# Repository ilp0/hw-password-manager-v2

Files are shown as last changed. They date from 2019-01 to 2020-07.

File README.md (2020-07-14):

# HW Password Manager V2

[Youtube Video](https://www.youtube.com/watch?v=QssnJo2gxCg)

## Libraries needed:

[SSD1306Ascii](https://github.com/greiman/SSD1306Ascii)

[RFID](https://github.com/miguelbalboa/rfid)

[SD](https://github.com/arduino-libraries/SD)

[rBase64](https://github.com/boseji/rBASE64)

[DigitalIO](https://github.com/greiman/DigitalIO)

[SPI](https://www.arduino.cc/en/reference/SPI)

## Wiring

### SSD1306 display

| SSD1306 Pin 	| Pro Micro Pin 	|
|-	|-	|
| GND 	| GND 	|
| VCC 	| 5V 	|
| SCL 	| SCL 	|
| SDA 	| SDA 	|

### RC522 RFID 

| RC522 	| Pro Micro Pin 	|
|-	|-	|
| SS(component most likely says SDA) 	| 8 	|
| MISO 	| MISO (14) 	|
| MOSI 	| MOSI (16) 	|
| SCK 	| SCLK (15) 	|
| RST 	| 4 	|
| GND 	| GND 	|
| 3.3V 	| 3.3V 	|

### Micro SD card reader

| SD Card reader 	| Pro Micro Pin 	|
|-	|-	|
| SS 	| 10 	|
| MISO 	| MISO (14) 	|
| MOSI 	| MOSI (16) 	|
| SCK 	| SCLK (15) 	|
| GND 	| GND 	|
| 3.3V 	| 3.3V 	|

### Joystick

| Joystick | Pro Micro Pin |
|- |- |
| VCC | VCC|
| Y | A1 |
| GND | GND |
| X | A0 |

### Push buitton

Pro Micro Pin 9

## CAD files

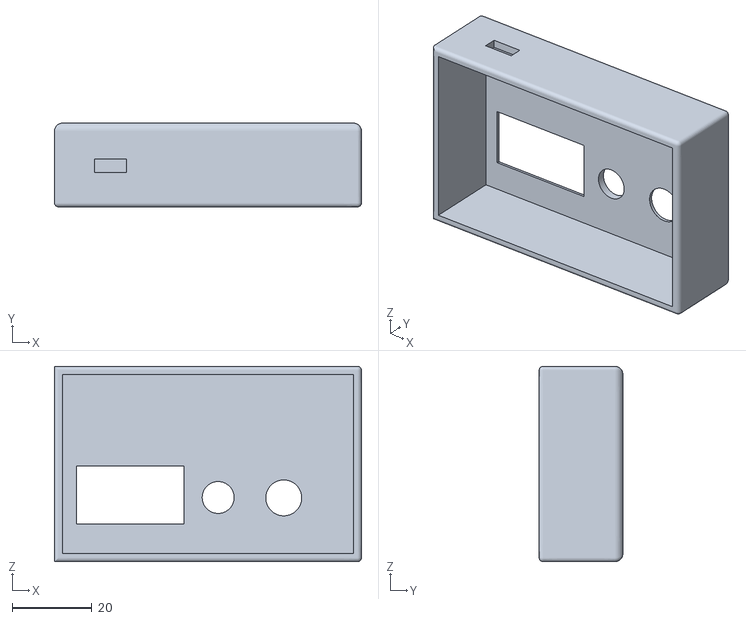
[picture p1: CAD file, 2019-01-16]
3d/password-manager-v2-case-top.stl
77.0 x 21.0 x 49.0

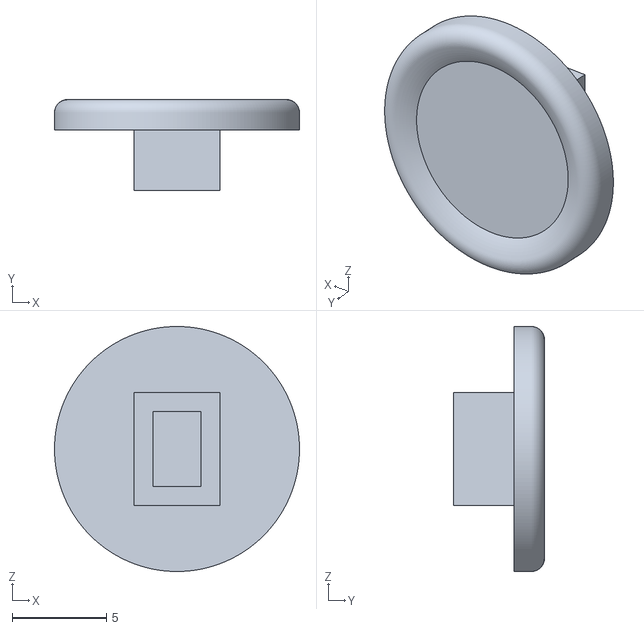
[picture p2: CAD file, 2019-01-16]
3d/password-manager-v2-thumbstick.stl
13.0 x 4.83 x 13.0

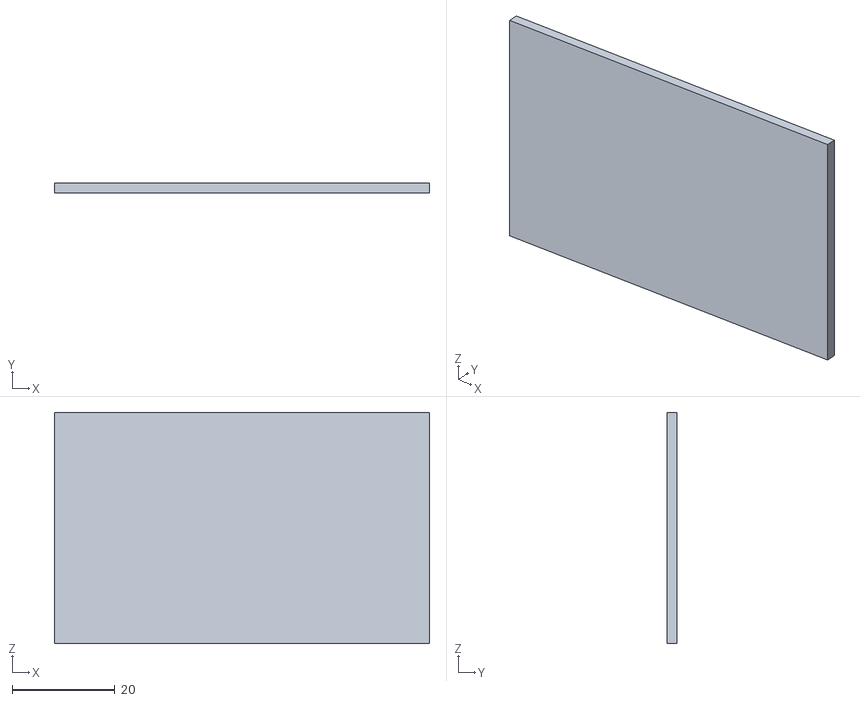
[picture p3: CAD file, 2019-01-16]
3d/password-manager-v2-case-bottom.stl
73.0 x 2.00 x 45.0

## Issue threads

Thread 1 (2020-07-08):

Rfid library

Zeskye, 2020-07-08:
First of all thanks for your quick reply. I have downloaded and installed all library that you put in the readme, but after compilation of the hardware-password-manager-V2.ino, im getting a lot of error, first of all the RFID.h library is not found because the library linked for the RFID is the MFRC522.h, and even by replacing RFID.h by MFRC522.h it's not working.

 Arduino : 1.8.12 (Windows 10), Carte : "Arduino Micro"

In file included from C:\Program Files (x86)\Arduino\libraries\SD\src/utility/Sd2Card.h:26:0,

                 from C:\Program Files (x86)\Arduino\libraries\SD\src/utility/SdFat.h:29,

                 from C:\Program Files (x86)\Arduino\libraries\SD\src/SD.h:20,

                 from C:\Users\Zeskye\Documents\hw-password-manager-v2-master_2\hw-password-manager-v2-master\hardware-password-manager-v2\hardware-password-manager-v2.ino:15:

C:\Program Files (x86)\Arduino\libraries\SD\src/utility/Sd2PinMap.h:463:9: error: ambiguating new declaration of 'uint8_t badPinNumber()'

 uint8_t badPinNumber(void)

         ^~~~~~~~~~~~

In file included from C:\Users\Zeskye\Documents\Arduino\libraries\DigitalIO-master\src/DigitalIO.h:31:0,

                 from C:\Users\Zeskye\Documents\hw-password-manager-v2-master_2\hw-password-manager-v2-master\hardware-password-manager-v2\hardware-password-manager-v2.ino:9:

C:\Users\Zeskye\Documents\Arduino\libraries\DigitalIO-master\src/DigitalPin.h:47:6: note: old declaration 'void badPinNumber()'

 void badPinNumber(void)

      ^~~~~~~~~~~~

In file included from C:\Program Files (x86)\Arduino\libraries\SD\src/utility/Sd2Card.h:26:0,

                 from C:\Program Files (x86)\Arduino\libraries\SD\src/utility/SdFat.h:29,

                 from C:\Program Files (x86)\Arduino\libraries\SD\src/SD.h:20,

                 from C:\Users\Zeskye\Documents\hw-password-manager-v2-master_2\hw-password-manager-v2-master\hardware-password-manager-v2\hardware-password-manager-v2.ino:15:

C:\Program Files (x86)\Arduino\libraries\SD\src/utility/Sd2PinMap.h: In function 'uint8_t getPinMode(uint8_t)':

C:\Program Files (x86)\Arduino\libraries\SD\src/utility/Sd2PinMap.h:471:25: error: void value not ignored as it ought to be

     return badPinNumber();

                         ^

C:\Program Files (x86)\Arduino\libraries\SD\src/utility/Sd2PinMap.h: In function 'uint8_t fastDigitalRead(uint8_t)':

C:\Program Files (x86)\Arduino\libraries\SD\src/utility/Sd2PinMap.h:487:9: error: ambiguating new declaration of 'uint8_t fastDigitalRead(uint8_t)'

 uint8_t fastDigitalRead(uint8_t pin) {

         ^~~~~~~~~~~~~~~

In file included from C:\Users\Zeskye\Documents\Arduino\libraries\DigitalIO-master\src/DigitalIO.h:31:0,

                 from C:\Users\Zeskye\Documents\hw-password-manager-v2-master_2\hw-password-manager-v2-master\hardware-password-manager-v2\hardware-password-manager-v2.ino:9:

C:\Users\Zeskye\Documents\Arduino\libraries\DigitalIO-master\src/DigitalPin.h:127:6: note: old declaration 'bool fastDigitalRead(uint8_t)'

 bool fastDigitalRead(uint8_t pin) {

      ^~~~~~~~~~~~~~~

In file included from C:\Program Files (x86)\Arduino\libraries\SD\src/utility/Sd2Card.h:26:0,

                 from C:\Program Files (x86)\Arduino\libraries\SD\src/utility/SdFat.h:29,

                 from C:\Program Files (x86)\Arduino\libraries\SD\src/SD.h:20,

                 from C:\Users\Zeskye\Documents\hw-password-manager-v2-master_2\hw-password-manager-v2-master\hardware-password-manager-v2\hardware-password-manager-v2.ino:15:

C:\Program Files (x86)\Arduino\libraries\SD\src/utility/Sd2PinMap.h:491:25: error: void value not ignored as it ought to be

     return badPinNumber();

                         ^

In file included from C:\Users\Zeskye\Documents\Arduino\libraries\SSD1306Ascii-master\src/SSD1306AsciiAvrI2c.h:26:0,

                 from C:\Users\Zeskye\Documents\hw-password-manager-v2-master_2\hw-password-manager-v2-master\hardware-password-manager-v2\hardware-password-manager-v2.ino:19:

C:\Users\Zeskye\Documents\Arduino\libraries\SSD1306Ascii-master\src/utility/AvrI2c.h: At global scope:

C:\Users\Zeskye\Documents\Arduino\libraries\SSD1306Ascii-master\src/utility/AvrI2c.h:29:15: error: redefinition of 'const uint8_t I2C_READ'

 uint8_t const I2C_READ = 1;

               ^~~~~~~~

In file included from C:\Users\Zeskye\Documents\Arduino\libraries\DigitalIO-master\src/DigitalIO.h:32:0,

                 from C:\Users\Zeskye\Documents\hw-password-manager-v2-master_2\hw-password-manager-v2-master\hardware-password-manager-v2\hardware-password-manager-v2.ino:9:

C:\Users\Zeskye\Documents\Arduino\libraries\DigitalIO-master\src/I2cConstants.h:51:15: note: 'const uint8_t I2C_READ' previously defined here

 const uint8_t I2C_READ = 1;

               ^~~~~~~~

In file included from C:\Users\Zeskye\Documents\Arduino\libraries\SSD1306Ascii-master\src/SSD1306AsciiAvrI2c.h:26:0,

                 from C:\Users\Zeskye\Documents\hw-password-manager-v2-master_2\hw-password-manager-v2-master\hardware-password-manager-v2\hardware-password-manager-v2.ino:19:

C:\Users\Zeskye\Documents\Arduino\libraries\SSD1306Ascii-master\src/utility/AvrI2c.h:32:15: error: redefinition of 'const uint8_t I2C_WRITE'

 uint8_t const I2C_WRITE = 0;

               ^~~~~~~~~

In file included from C:\Users\Zeskye\Documents\Arduino\libraries\DigitalIO-master\src/DigitalIO.h:32:0,

                 from C:\Users\Zeskye\Documents\hw-password-manager-v2-master_2\hw-password-manager-v2-master\hardware-password-manager-v2\hardware-password-manager-v2.ino:9:

C:\Users\Zeskye\Documents\Arduino\libraries\DigitalIO-master\src/I2cConstants.h:54:15: note: 'const uint8_t I2C_WRITE' previously defined here

 const uint8_t I2C_WRITE = 0;

               ^~~~~~~~~

hardware-password-manager-v2:46:9: error: expected constructor, destructor, or type conversion before '(' token

 mfrc522 (RFID_SS_PIN, RST_PIN) ;

         ^

C:\Users\Zeskye\Documents\hw-password-manager-v2-master_2\hw-password-manager-v2-master\hardware-password-manager-v2\hardware-password-manager-v2.ino: In function 'void setup()':

hardware-password-manager-v2:81:3: error: 'mfrc522' was not declared in this scope

   mfrc522.init();

   ^~~~~~~

C:\Users\Zeskye\Documents\hw-password-manager-v2-master_2\hw-password-manager-v2-master\hardware-password-manager-v2\hardware-password-manager-v2.ino: In function 'void temp()':

hardware-password-manager-v2:114:7: error: 'mfrc522' was not declared in this scope

   if (mfrc522.readCardSerial())

       ^~~~~~~

hardware-password-manager-v2:122:3: error: 'mfrc522' was not declared in this scope

   mfrc522.halt();

   ^~~~~~~

C:\Users\Zeskye\Documents\hw-password-manager-v2-master_2\hw-password-manager-v2-master\hardware-password-manager-v2\hardware-password-manager-v2.ino: In function 'void generateCreds()':

C:\Users\Zeskye\Documents\hw-password-manager-v2-master_2\hw-password-manager-v2-master\hardware-password-manager-v2\hardware-password-manager-v2.ino:258:21: warning: ISO C++ forbids converting a string constant to 'char*' [-Wwrite-strings]

   char *alphabeth = "abcdefghijklmnopqrstuvwxyzABCDEFGHIJKLMNOPQRSTUVWXYZ0123456789'?^&/%$£-+";

                     ^~~~~~~~~~~~~~~~~~~~~~~~~~~~~~~~~~~~~~~~~~~~~~~~~~~~~~~~~~~~~~~~~~~~~~~~~~~

C:\Users\Zeskye\Documents\hw-password-manager-v2-master_2\hw-password-manager-v2-master\hardware-password-manager-v2\hardware-password-manager-v2.ino:260:16: warning: ISO C++ forbids converting a string constant to 'char*' [-Wwrite-strings]

   char *pass = "";

                ^~

C:\Users\Zeskye\Documents\hw-password-manager-v2-master_2\hw-password-manager-v2-master\hardware-password-manager-v2\hardware-password-manager-v2.ino:278:16: warning: unknown escape sequence: '\;'

     newPass += "\;";

                ^~~~

C:\Users\Zeskye\Documents\hw-password-manager-v2-master_2\hw-password-manager-v2-master\hardware-password-manager-v2\hardware-password-manager-v2.ino: In function 'void loop()':

hardware-password-manager-v2:384:10: error: 'mfrc522' was not declared in this scope

     if (!mfrc522.isCard())

          ^~~~~~~

Plusieurs bibliothèque trouvées pour "SD.h"
Utilisé : C:\Program Files (x86)\Arduino\libraries\SD
Non utilisé : C:\Users\Zeskye\Documents\Arduino\libraries\SD-master
exit status 1
expected constructor, destructor, or type conversion before '(' token

Ce rapport pourrait être plus détaillé avec
l'option "Afficher les résultats détaillés de la compilation"
activée dans Fichier -> Préférences.

ilp0, 2020-07-14:
Hey Zeskye!

I added the RFID library I used. I used an old version of the linked library.

Also, if you're using a Sparkfun Pro Micro(or a clone), have you gone through the [installation steps](https://learn.sparkfun.com/tutorials/pro-micro--fio-v3-hookup-guide)? You should have the Pro Micro board selected when you build/verify the code.

Closed 2020-08-12.

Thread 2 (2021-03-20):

BOARD ERROR

unkn0wn-wifi, 2021-03-20:
Hi there,
My name is sanjai and im a cyber security researcher student, i have a youtube channel related to this https://www.youtube.com/channel/UCrxx_lAmF_Lv5laNLnPBIPw

So ive recently came upon your project and have come really interested in it, so i gathered all the parts and bought them on aliexpress, after waiting for a month all of them arrived i stuck them ont a breadboard and tried uploading the code to recieve a

"Error compiling for Sparkfun Pro Micro"

So i need your help can you please guide me through how to mitigate this issue and some steps on how to set this up as there is very little documentation on how to set this up plz as after assembling i will be reviewing this on my youtube channel
, if you can please contact me via discord ill be happy to speak to you! sanjai#1186

Looking forward for your reply

Sanjai

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

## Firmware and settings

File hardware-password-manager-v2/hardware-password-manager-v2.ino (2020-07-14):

/*
    HARDWARE PASSWORD MANAGER
    Author: Ilpo Loikkanen
*/


//base64
#include <rBase64.h>

//software SPI
#include <DigitalIO.h>

// RC522 rfid
#include "RFID_lib/rfid.h"

//SD card
#include <SD.h>

//128x64 OLED display. Using ascii library for smaller size
#include <SSD1306Ascii.h>
#include <SSD1306AsciiAvrI2c.h>
#include <SSD1306init.h>

//KB and mouse emulation
#include <Keyboard.h>
#include <Mouse.h>

//hardware SPI
#include <SPI.h>

//RFID PINS
#define RFID_SS_PIN 8
#define RST_PIN 4

//SD CARD PIN
#define SD_SS_PIN 10

//SCREEN STUFF
#define I2C_ADDRESS 0x3C
SSD1306AsciiAvrI2c display;

//other defines
#define PASSWORD_SIZE  8
#define PASS_ARR_SIZE  20
#define STRING_ARRAY_SIZE(x) sizeof(x)/sizeof(x[0])

//RFID STUFF
RFID mfrc522 (RFID_SS_PIN, RST_PIN) ;
unsigned long RFID;
String readid;

//passwords and cards
String card1 = ""; //card
String card2 = ""; //keychain
byte password[PASSWORD_SIZE] = {3, 3, 3, 3, 3, 3, 3, 3};
byte pw_input[PASSWORD_SIZE];
byte curDigit = 0;

//joystick stuff
int joyPin1 = 1;
int joyPin2 = 0;

//other stuff
bool unlocked = false;
int page = 0;
int sel = 0;
String passwords[PASS_ARR_SIZE][2];
String menuItems[2][2] = {
  {"Create new", "Delete"},
  {"Mouse Mode", "Change key"},

};

//Encryption stuff
uint8_t key[] = {0, 1, 2, 3, 4, 5, 6, 7, 8, 9, 10, 11, 12, 13, 14, 15}; //CHANGE THIS!!!
File secret;

void setup()
{
  display.begin(&Adafruit128x64, I2C_ADDRESS);
  display.setFont(Iain5x7);
  SPI.begin();
  mfrc522.init();
  if (!SD.begin(10)) {
    display.println("SD CARD initialization failed!");
    return;
  }
  bootAnim();
  pinMode(9, INPUT);
  display.clear();
  display.set2X();
  display.setCursor(7, 2);
  display.println("AUTHENTICATE");
  display.setCursor(9, 5);
  display.println("______________");
  display.setCursor(20, 4);
  //rfid
  Keyboard.begin();

}

void bootAnim() {
  //todo
  for (int x = 0; x < 127; x++){
    for (int y = 0; y < 8; y++){
      display.setCursor(127-x,y);
      display.print("x");
      delay(1);
    }
  }
}

void temp()
{
  readid = "";
  if (mfrc522.readCardSerial())
  {
    for (int i = 0; i <= 4; i++) //card value: "xyz xyz xyz xyz xyz" (15 digits maximum; 5 pairs of xyz)hence 0<=i<=4 //
    {
      RFID = mfrc522.serNum[i];
      readid += RFID; // store RFID value into string "cardNum" and concatinate it with each iteration
    }
  }
  mfrc522.halt();
}

//get joystick direction, using psp joystick.
byte getDirection(int x, int y) {
  byte dir = 0;
  if (x >= 450 && x <= 550 && y >= 400 && y <= 480) dir = 0;              //CENTER
  else if (x >= 200 && x <= 370  && y >= 500 && y <= 660) dir = 1;        //UP
  else if (x >= 560 && x <= 700  && y >= 150 && y <= 300) dir = 2;        //DOWN
  else if (x >= 370 && x <= 460  && y >= 560 && y <= 700) dir = 3;        //LEFT
  else if (x >= 700 && x <= 900  && y >= 250 && y <= 400) dir = 4;        //RIGTH
  else dir = 5;    //UNKNOWN
  return dir;
}

void showMenu(int index, String items[][2], String title, int arrSize) {
  if (index >= arrSize) index = 0;
  if (index < 0) index = arrSize - 1;
  display.clear();
  display.set2X();
  display.println(title);
  display.set1X();
  //print menuitems
  if (page != 0) {
    for (int i = 0; i < arrSize && i < 6; i++) {
      if (arrSize >= i) {
        if (index < 6) display.println("   " + items[page - 1][i]);
        else display.println("   " + items[page - 1][i + index - 6]);
      }
    }
  } else {

    //print password menu
    for (int i = 0; i < arrSize && i < 6; i++) {
      if (index < 6) display.println("   " + items[i][0]);
      else display.println("   " + items[(i + index) - 5][0]);

    }
  }
  //print selector
  if (index < arrSize) {
  } else index = 0;
  display.setRow(2 + index);
  if (index > 6) display.setRow(7);
  display.setCol(0);
  display.print(">");
  sel = index;

}
void showSuccess() {
  display.clear();
  display.set2X();
  display.print("Success");
  delay(1500);
}

void showFail() {
  display.clear();
  display.set2X();
  display.print("Action failed.");
  delay(1500);
}

void inputPass(int i) {
  display.clear();
  display.set2X();
  display.println("UP Input");
  display.println("RIGHT Copy");
  display.println("DOWN Show");
  display.println("LEFT Cancel");
  while (getDirection(analogRead(joyPin1), analogRead(joyPin2)) != 0 || getDirection(analogRead(joyPin1), analogRead(joyPin2)) != 5) {
    switch (getDirection(analogRead(joyPin1), analogRead(joyPin2))) {
      case 1:
        Keyboard.print(passwords[i][1]);
        Keyboard.press(KEY_RETURN);
        Keyboard.releaseAll();
        showSuccess();
        return;
        break;
      case 2:
        display.clear();
        display.setCursor(0, 0);
        display.set2X();
        display.println("USER");
        display.set1X();
        display.println(passwords[i][0]);
        display.set2X();
        display.println("PW");
        display.set1X();
        display.print(passwords[i][1]);
        display.println("\nPress the button to exit.");
        while (digitalRead(9) != HIGH);
        delay(500);
        return;
        break;
      case 3:
        return;
        break;
      case 4:
        Keyboard.print(passwords[i][1]);
        Keyboard.press(KEY_RIGHT_SHIFT);
        for (int i = 0; i < passwords[i][1].length(); i++) {
          Keyboard.press(KEY_LEFT_ARROW);
          Keyboard.release(KEY_LEFT_ARROW);
        }
        Keyboard.release(KEY_RIGHT_SHIFT);
        Keyboard.press(KEY_LEFT_CTRL);
        Keyboard.press('x');
        Keyboard.releaseAll();
        display.clear();
        showSuccess();
        return;
        break;
      default:
        delay(60);
        break;
    }
  }
  display.clear();
}
//read passwords from sd card
void refreshSDCard() {

  secret = SD.open("secret.txt");
  if (secret) {
    for (int i = 0; secret.available(); i++) {
      passwords[i][0] = secret.readStringUntil(';');
      passwords[i][1] = secret.readStringUntil('\n');
    }
    secret.close();
  } else {
    showFail();
  }
}
//generate new creds and write to sd card
void generateCreds() {
  char *alphabeth = "abcdefghijklmnopqrstuvwxyzABCDEFGHIJKLMNOPQRSTUVWXYZ0123456789'?^&/%$£-+";
  const long alphabethLength = 70;//sizeof(alphabeth);
  char *pass = "";
  display.clear();
  display.set1X();
  display.print("Hold a random\ndirection on \njoystick for randomness");
  display.set2X();
  delay(2000);
  randomSeed(analogRead(joyPin1)*analogRead(joyPin2) + millis());
  for (int n = 0; n < 20; n++)
  {
    pass += alphabeth[random(0, alphabethLength)];
  }
  pass += '\0';
  secret = SD.open("secret.txt", FILE_WRITE);
  if (secret) {
    String newPass =  "GEN-";
    newPass += pass[0];
    newPass += pass[1];
    newPass += pass[2];
    newPass += "\;";
    newPass += pass;
    newPass += "\n";
    secret.print(newPass);
    delay(100);
    showSuccess();
    secret.close();
  } else showFail();
  delay(500);
  refreshSDCard();
}

void mouseMode() {
  display.clear();
  display.set2X();
  display.println("MOUSE MODE");
  delay(200);
  Mouse.begin();
  bool isActive = true;
  int clickStart = 0;
  bool clickActive = false;
  while (isActive) {
    if (digitalRead(9) != HIGH) {
      if (clickActive) {
        Mouse.release();
        if ((millis() - clickStart) > 2000) isActive = false;
        clickActive = false;
        clickStart = 0;
        delay(300);
      }

      switch (getDirection(analogRead(joyPin1), analogRead(joyPin2))) {
        case 0:
          break;
        case 1:
          Mouse.move(0, -10, 0);
          break;
        case 2:
          Mouse.move(0, 10, 0);
          break;
        case 3:
          Mouse.move(-10, 0);
          break;
        case 4:
          Mouse.move(10, 0, 0);
          break;
        default:
          break;
      }
      delay(50);

    } else {
      if (clickActive == false) clickStart = millis();
      clickActive = true;
      Mouse.press();
    }
  }
}

void unlock() {
  unlocked = true;
  refreshSDCard();
  showMenu(sel, passwords, "Vault", PASS_ARR_SIZE);
}

void loop()
{
  //pasword and rfid unlock
  if (!unlocked) {
    byte curDir = getDirection(analogRead(joyPin1), analogRead(joyPin2));
    bool enterPress = false;
    if (digitalRead(9) == HIGH) enterPress = true;
    if ((curDir != 5 && curDir != 0) || enterPress)  {
      if (!enterPress) {
        pw_input[curDigit] = curDir;
        display.print("*");
        curDigit++;
      }
      if (curDigit >= PASSWORD_SIZE || enterPress) {
        delay(400);
        enterPress = false;
        bool isRight = true;
        for (int i = 0; i < PASSWORD_SIZE; i++) {
          if (pw_input[i] != password[i]) isRight = false;
        }
        if (isRight) {
          unlock();
        }
        else {
          display.clear();
          display.setCursor(7, 2);
          display.println("AUTHENTICATE");
          display.setCursor(9, 5);
          display.println("______________");
          display.setCursor(20, 4);
          display.println("ERROR!");
          delay(400);
          display.setCursor(5, 5);
          display.println("                           ");
          display.setCursor(5, 5);
          curDigit = 0;
        }
      }
      delay(100);

    }
    if (!mfrc522.isCard())
    {
      return;
    }
    temp();
    if (readid == card1 || readid == card2) unlock();
    else return;
  } else {
    //IF UNLOCKED
    if (digitalRead(9) == HIGH) {
      //menu select
      switch (page) {
        case 0:
          //passwords
          inputPass(sel);
          showMenu(sel, passwords, "VAULT", PASS_ARR_SIZE);
          return;
          break;
        case 1:
          //generate new
          generateCreds();
          showMenu(sel, menuItems, "GENERATE", 1);
          break;
        case 2:
          //Tools
          switch (sel) {
            case 0:
              mouseMode();
              showSuccess();
              break;
            default:
              break;
          }
          showMenu(sel, menuItems, "TOOLS", 2);
          break;
        case -1:
          page = 2;
          showMenu(sel, menuItems, "SETTINGS", 2);
          break;
        default:
          page = 0;
          showMenu(sel, passwords, "VAULT", PASS_ARR_SIZE);
          break;

      }
    }
    switch (getDirection(analogRead(joyPin1), analogRead(joyPin2))) {
      case 1:
        sel--;
        delay(200);
        break;
      case 2:
        sel++;
        delay(200);
        break;
      case 3:
        page--;
        delay(200);
        break;
      case 4:
        page++;
        delay(200);
        break;
      default:
        return;
        break;
    }

    switch (page) {
      case 0:
        //passwords
        showMenu(sel, passwords, "VAULT", PASS_ARR_SIZE);
        break;
      case 1:
        //generate new
        showMenu(sel, menuItems, "GENERATE", 1);
        break;
      case 2:
        //change password
        showMenu(sel, menuItems, "TOOLS", 2);
        break;
      case -1:
        page = 2;
        showMenu(sel, menuItems, "TOOLS", 2);
        break;
      default:
        page = 0;
        showMenu(sel, passwords, "VAULT", PASS_ARR_SIZE);
        break;
    }
    delay(50);
  }
}

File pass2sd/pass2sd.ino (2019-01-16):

//THIS PROGRAM WILL DELETE YOUR CURRENT PASSWORDS
#define SD_SS_PIN 10

//SCREEN STUFF
#define I2C_ADDRESS 0x3C
SSD1306AsciiAvrI2c display;

#include <SPI.h>
#include <SD.h>

#define PASS_ARR_SIZE   5
String passwordArray[PASS_ARR_SIZE][1] = {
  {"", ""},
  {"", ""},
  {"", ""},
  {"", ""},
  {"", ""}
}

File myFile;

void setup() {

  display.begin(&Adafruit128x64, I2C_ADDRESS);
  display.setFont(Iain5x7);
  display.println("INITIALIZING SD CARD");
  if (!SD.begin(SD_SS_PIM)) {
    display.println("SD INITIALIZATION FAILED!");
    return;
  }
  Serial.println("INITIALIZATION COMPLETE");

  // open the file. note that only one file can be open at a time,
  // so you have to close this one before opening another.
  if (SD.exists("secret.txt") SD.remove("secret.txt");
  myFile = SD.open("secret.txt", FILE_WRITE);

  // if the file opened okay, write to it:
  if (myFile) {
    display.println("Writing from flash to SD...");
    for (int i = 0; i < PASS_ARR_SIZE; i++) {
      myFile.println(passwordArray[i][0] + "\;" + passwordArray[i][1]);
    }
    // close the file:
    myFile.close();
    display.println("Writing succesful!");
    display.println("You can now reflash the password manager.");


  } else {
    // if the file didn't open, print an error:
    Serial.println("error opening secret.txt");
  }
}

void loop() {
  // nothing happens after setup
}

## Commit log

2019-01-16 first version
    [password-manager-v2-case-bottom.stl, password-manager-v2-case-top.stl, password-manager-v2-thumbstick.stl]
2019-01-16 fixed couple bugs
